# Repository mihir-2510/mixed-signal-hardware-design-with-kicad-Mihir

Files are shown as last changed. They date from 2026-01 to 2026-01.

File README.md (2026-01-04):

# USB-C Single-Channel Signal Analyzer & Generator

## Description
This repository contains the hardware design for a **USB-C powered, single-channel Signal Analyzer and Signal Generator** intended for low-frequency (audio-band) applications. The board integrates precision analog signal conditioning, data converters, and a microcontroller to enable waveform generation and signal acquisition through a PC interface.

The project was developed by Mihir Patil (Electrical Engineer) as a part of the deliverables for *Mixed-Signal Hardware Design with KiCad* course by Philip Salmony and focuses on applying **real-world mixed-signal PCB design practices** including power-domain separation, grounding strategies, filtering, biasing, and EMC-aware layout.

The module can function as a compact lab instrument for experimentation, education, and prototyping.

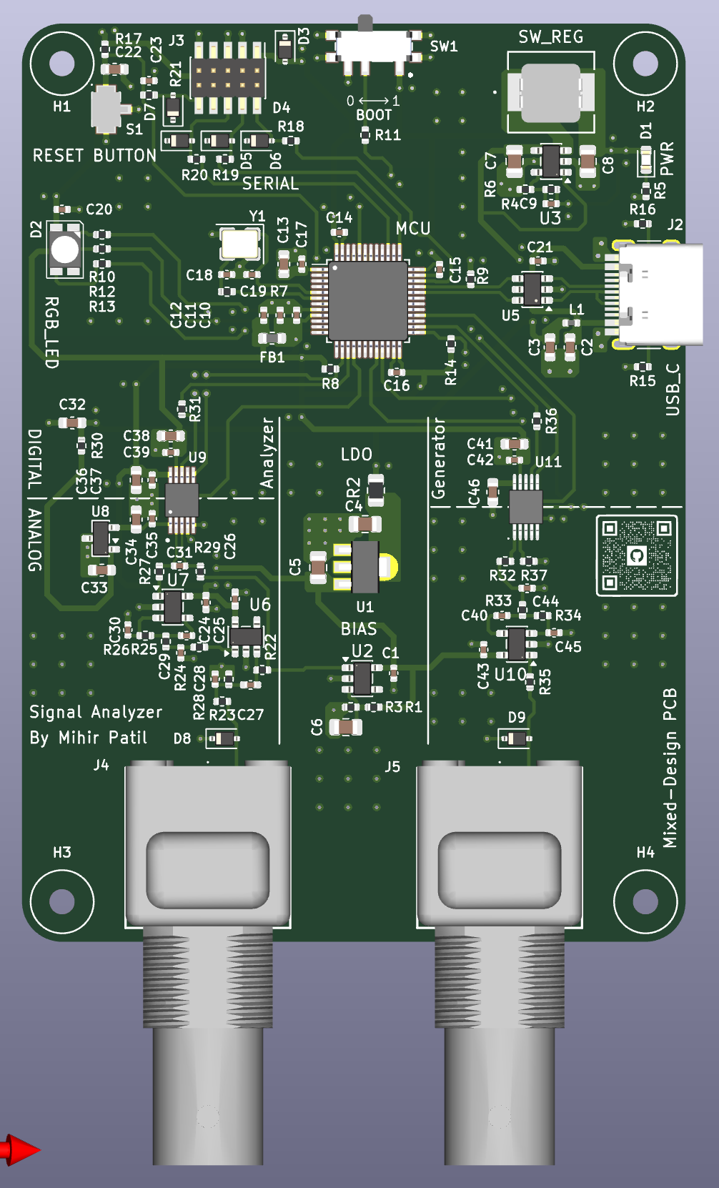
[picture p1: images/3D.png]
PCB 3D View


---

## Components

### Microcontroller
- STM32F103 (ARM Cortex-M series)
- USB 2.0 Full-Speed device
- SPI interfaces for ADC and DAC
- SWD interface for programming and debugging
- External crystal for accurate timing

### Analog-to-Digital Converter (ADC)
- 14-bit resolution
- Audio-band sampling rates
- High-impedance buffered input
- AC-coupled front end
- 3rd-order Sallen-Key Butterworth anti-aliasing filter
- Precision voltage reference for improved accuracy

### Digital-to-Analog Converter (DAC)
- 12-bit resolution
- SPI-controlled
- Reconstruction filter to suppress switching artifacts
- 50 Ω output impedance for signal integrity

### Power Architecture
- USB-C input power (5 V, < 500 mA)
- Switching buck regulator for digital 3.3 V rail
- Low-noise LDO regulator for analog 3.3 V rail
- Input LC filtering to suppress USB noise
- Dedicated mid-supply bias generator for single-supply analog stages

### Interfaces & Peripherals
- USB-C with CC resistors and ESD protection
- BNC connectors for signal input and output
- RGB status LED
- Reset and boot configuration buttons
- SWD debug header with protection components

---

## PCB Layout

The PCB was designed following mixed-signal layout best practices:
- Clear separation of analog and digital sections
- Dedicated analog and digital power domains
- Short return paths and solid ground referencing
- Careful placement of ADC/DAC front-end components
- EMI-aware routing for USB and high-speed digital lines

### Top-Level Board Layout
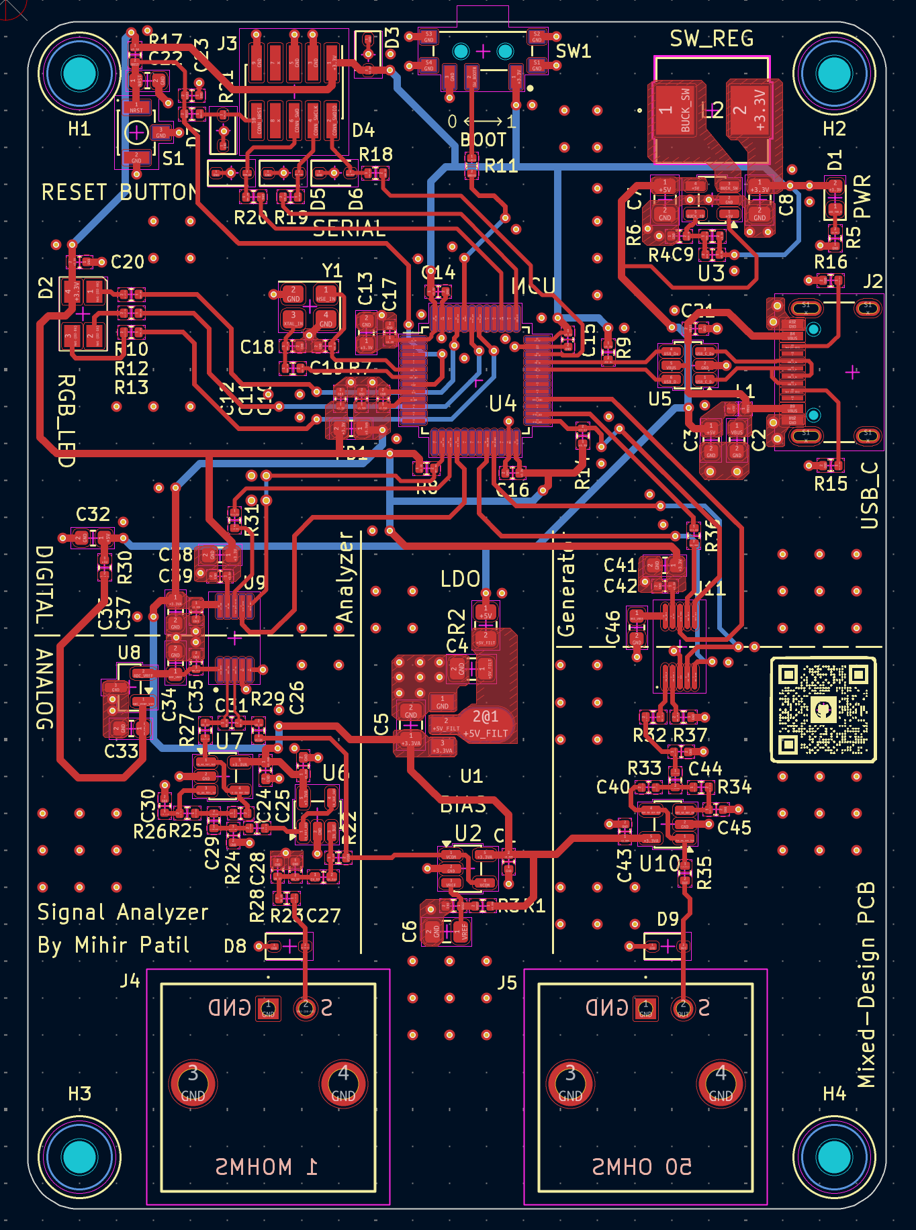
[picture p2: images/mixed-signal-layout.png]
PCB Layout


---

## Schematics

### Analog Front-End & ADC
High-impedance input buffer, RF filtering, AC coupling, and 3rd-order Butterworth anti-aliasing filter feeding the 14-bit ADC.

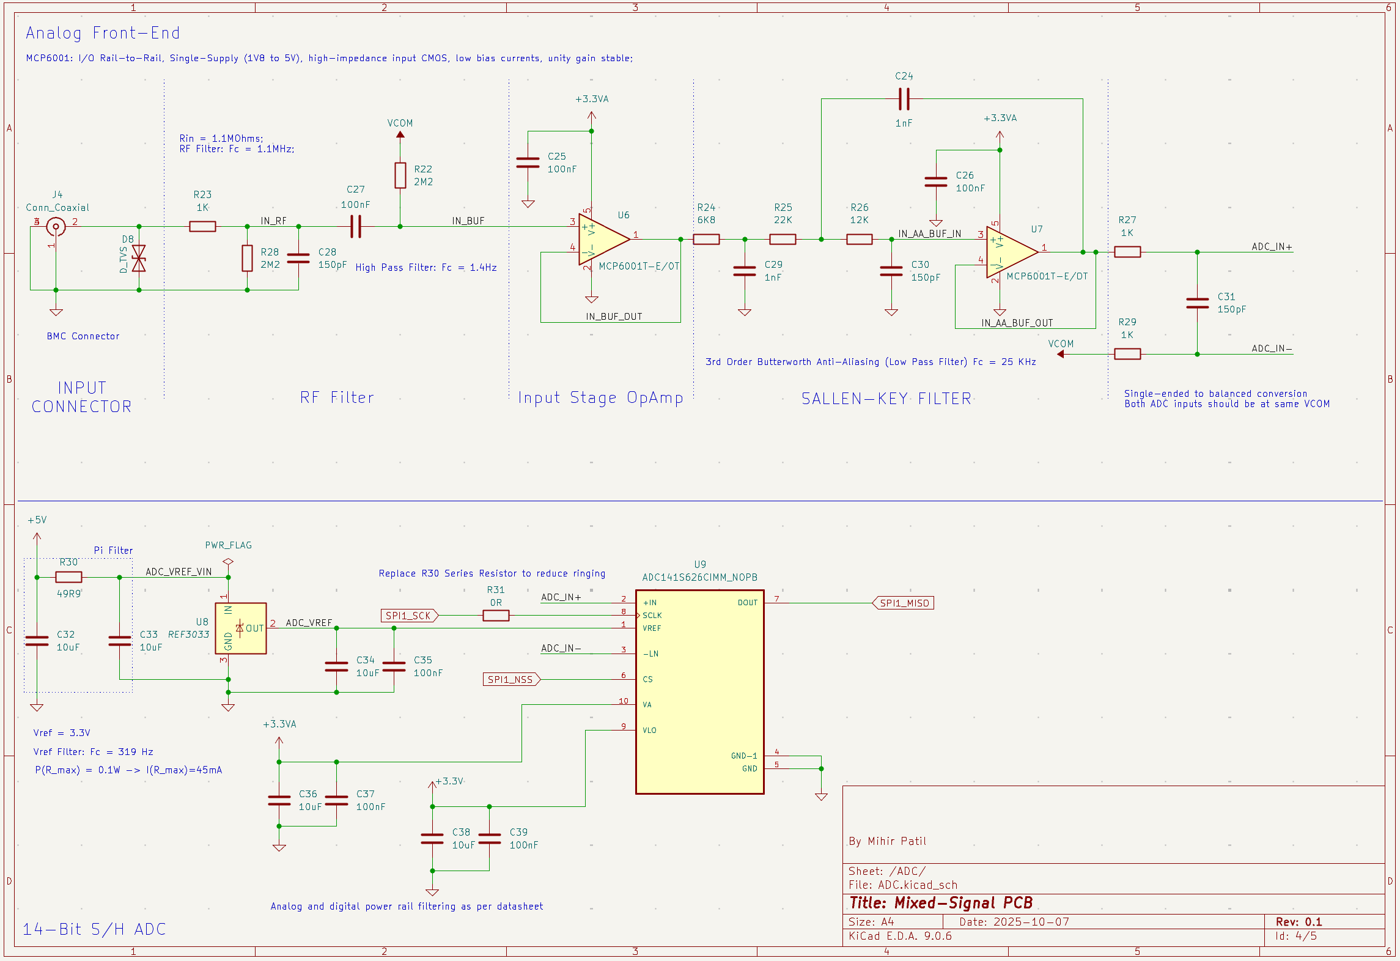
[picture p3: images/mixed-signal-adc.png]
Analog Front-End & ADC


---

### DAC & Analog Output Stage
DAC with reconstruction filter, output buffer, and 50 Ω output termination for clean waveform generation.

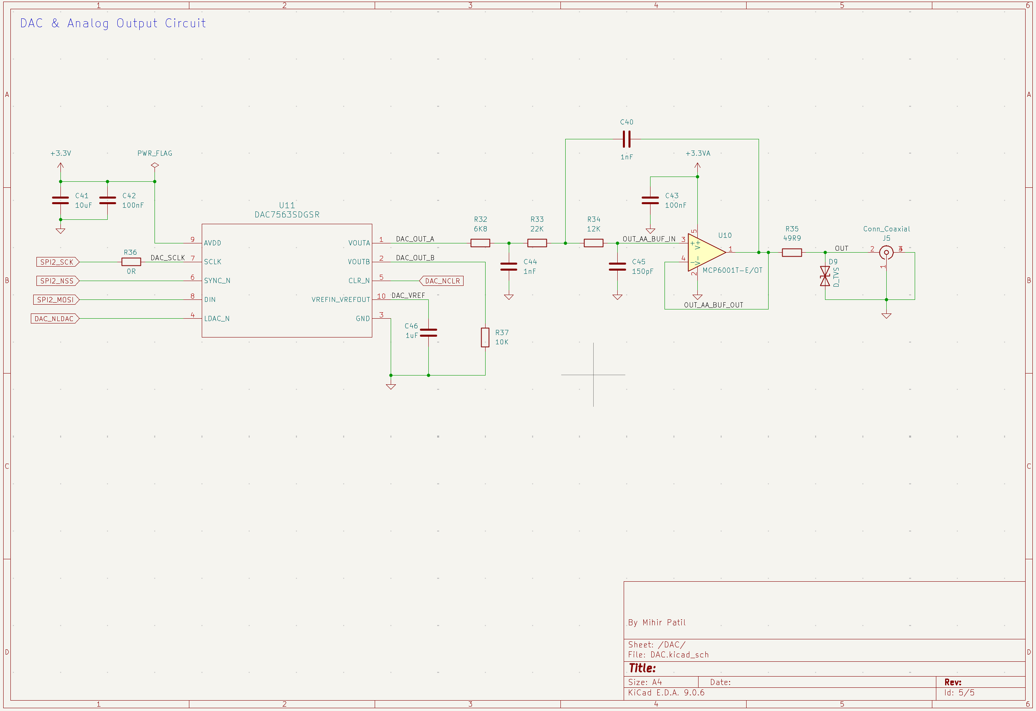
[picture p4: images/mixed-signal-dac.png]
DAC & Analog Output


---

### Microcontroller, USB-C & Debug
STM32 MCU core with USB-C interface, SWD debug circuitry, clocking, reset, and status LEDs.

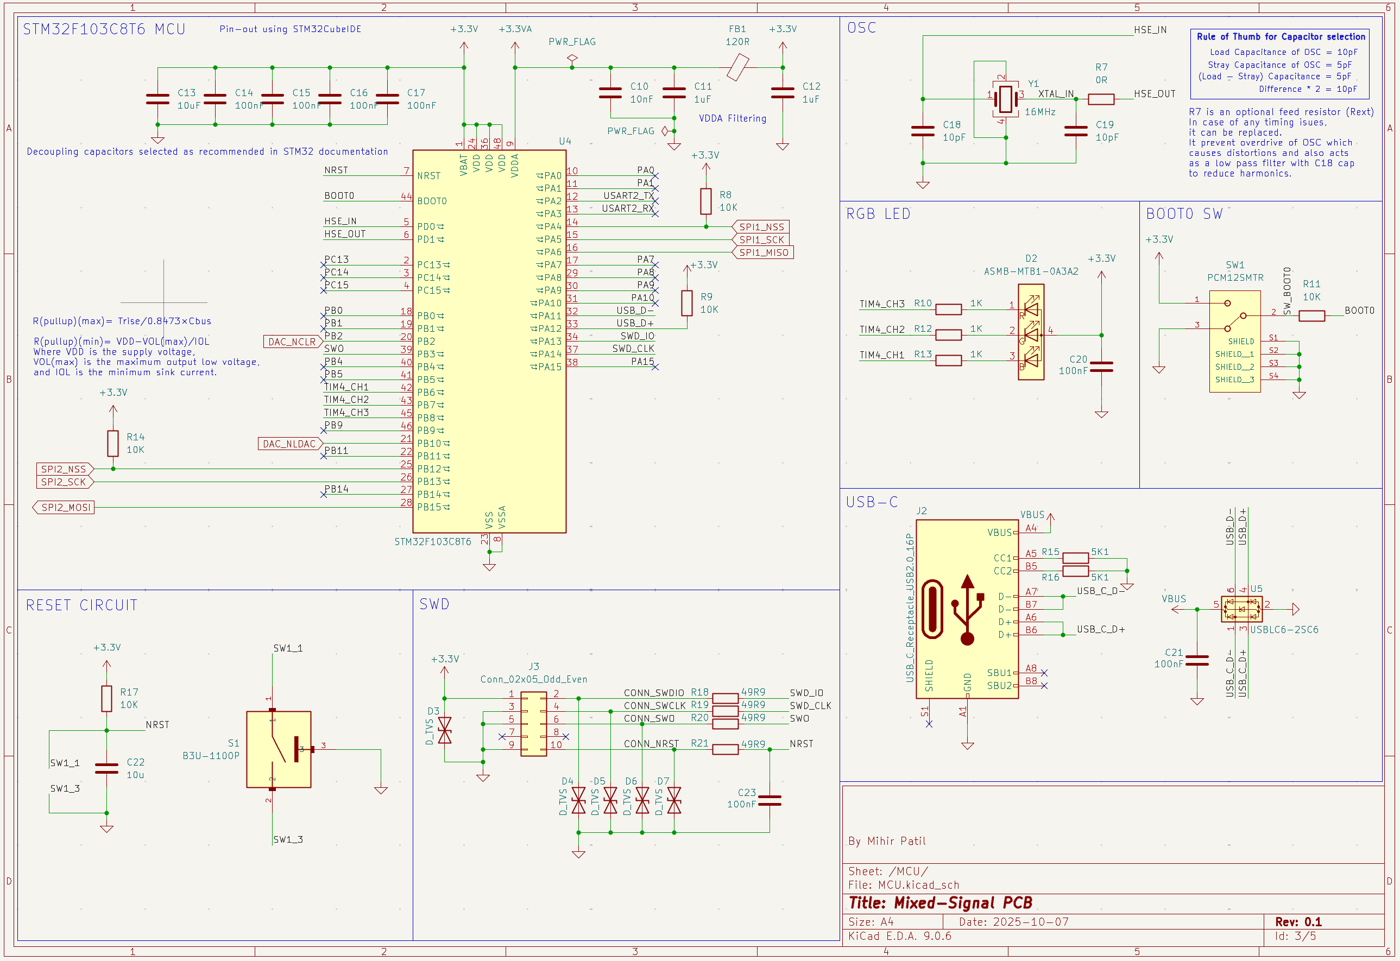
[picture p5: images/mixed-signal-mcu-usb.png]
MCU & USB


---

### Power Supply & Bias Generation
USB-C input filtering, buck regulator for digital rail, LDO for analog rail, and mid-supply bias generator.

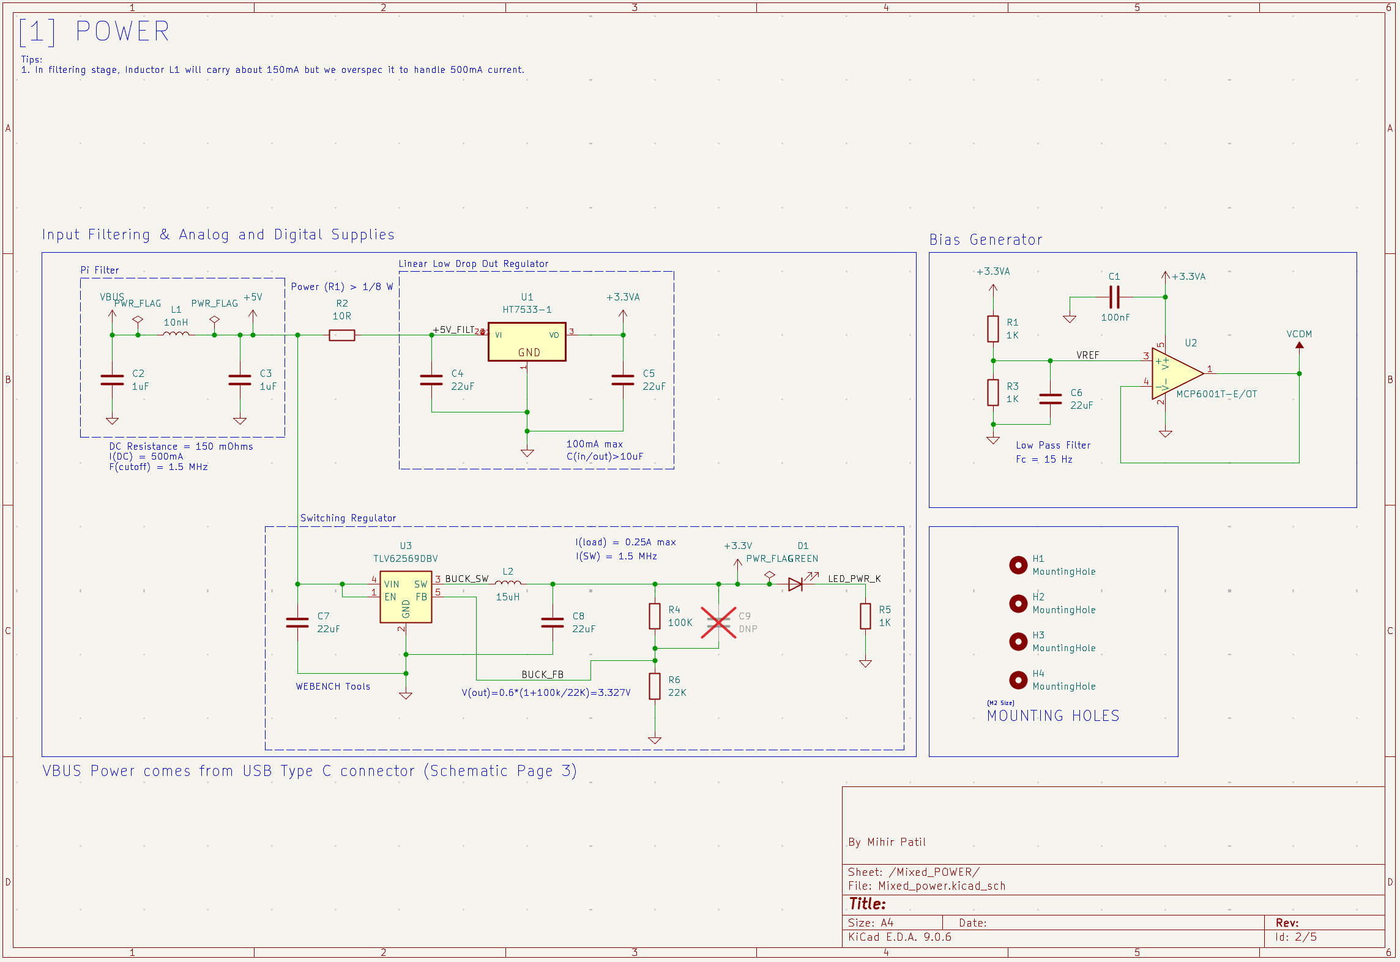
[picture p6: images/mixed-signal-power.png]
Power & Bias


---

## Use Cases

- **Low-Frequency Signal Analyzer**  
  Capture and inspect audio-band signals with proper buffering, filtering, and quantization.

- **Arbitrary Signal Generator**  
  Generate sine, square, and custom waveforms for testing analog circuits.

- **Educational Mixed-Signal Platform**  
  Demonstrates practical ADC/DAC interfacing, analog front-end design, and power integrity concepts.

- **PC-Based Measurement Tool**  
  Can be used as a simple oscilloscope or waveform generator when paired with host-side software.

---

## References

- Mixed-Signal Hardware Design with KiCad  
  Course by Philip Salmony  
  https://fedevel.com/courses/mixed-signal-hardware-design-with-kicad

- Phil’s Lab  
  https://www.phils-lab.net  
  https://www.youtube.com/@PhilsLab

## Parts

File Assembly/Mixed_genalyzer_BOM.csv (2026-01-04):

DESIGNATOR | QTY | Value | DNP | Exclude from BOM | Exclude from Board | Footprint | Datasheet | MANUFACTURER | Manufacturer_Part_Number | LCSC Part #
C1,C14,C15,C16,C17,C20,C21,C23,C35,C37,C39,C42,C43 | 13 | 100nF |  |  |  | Capacitor_SMD:C_0402_1005Metric | ~ | AIDE CAPACITOR | 0402X7R104K250NT | C48579248
C2,C3,C46 | 3 | 1uF |  |  |  | Capacitor_SMD:C_0603_1608Metric | ~ | AIDE CAPACITOR | 0603X5R105K160NT | C49326357
C4,C5,C6,C7,C8 | 5 | 22uF |  |  |  | Capacitor_SMD:C_0805_2012Metric | ~ | AIDE CAPACITOR | 0805X5R226M160NT | C49326686
C10 | 1 | 10nF |  |  |  | Capacitor_SMD:C_0402_1005Metric | ~ | AIDE CAPACITOR | 0402X7R103K500NT | C48579246
C11,C12 | 2 | 1uF |  |  |  | Capacitor_SMD:C_0402_1005Metric | ~ | Samsung Electro-Mechanics | CL05A105KP5NNNC | C14445
C13,C32,C33,C34,C36,C38,C41 | 7 | 10uF |  |  |  | Capacitor_SMD:C_0603_1608Metric | ~ | AIDE CAPACITOR | 0603X5R106M100NT | C48579264
C18,C19 | 2 | 10pF |  |  |  | Capacitor_SMD:C_0402_1005Metric | ~ | YAGEO | CC0402JRNPO9BN100 | C106199
C22 | 1 | 10u |  |  |  | Capacitor_SMD:C_0603_1608Metric | ~ | AIDE CAPACITOR | 0603X5R106M100NT | C48579264
C24,C29,C40,C44 | 4 | 1nF |  |  |  | Capacitor_SMD:C_0402_1005Metric | ~ | FOJAN | FCC0402B102K500AT | C5137470
C25,C26,C27 | 3 | 100nF |  |  |  | Capacitor_SMD:C_0402_1005Metric_Pad0.74x0.62mm_HandSolder | ~ | AIDE CAPACITOR | 0402X7R104K160NT | C48579247
C28,C30,C31,C45 | 4 | 150pF |  |  |  | Capacitor_SMD:C_0402_1005Metric | ~ | FH | 0402B151K500NT | C1527
D1 | 1 | GREEN |  |  |  | LED_SMD:LED_0603_1608Metric | ~ | BrtLed | BL-HGK36G-AV-TRB | C5123500
D2 | 1 | ASMB-MTB1-0A3A2 |  |  |  | LED_SMD:LED_Avago_PLCC4_3.2x2.8mm_CW | https://docs.broadcom.com/docs/AV02-4194EN | Broadcom | ASMB-MTB1-0A3A2 | C2927824
D3,D4,D5,D6,D7,D8,D9 | 7 | D_TVS |  |  |  | Diode_SMD:D_SOD-323 | ~ | GOODWORK | PESD3V3L1BA | C22466620
FB1 | 1 | 120R |  |  |  | Inductor_SMD:L_0603_1608Metric | ~ | UNI-ROYAL | 0603WAF1200T5E | C22787
H1,H2,H3,H4 | 4 | MountingHole |  | Excluded from BOM |  | MountingHole:MountingHole_2.2mm_M2 | ~
J2 | 1 | USB_C_Receptacle_USB2.0_16P |  |  |  | Connector_USB:USB_C_Receptacle_HRO_TYPE-C-31-M-12 | https://www.usb.org/sites/default/files/documents/usb_type-c.zip | Global Connector Technology | USB4105-GF-A-120 | C5184243
J3 | 1 | Conn_02x05_Odd_Even |  |  |  | Connector_PinHeader_1.27mm:PinHeader_2x05_P1.27mm_Vertical_SMD | ~ | hanxia | HX PZ1.27-2x5P TP | C41376037
J4,J5 | 2 | Conn_Coaxial |  |  |  | BMC:03156401010 | ~ | kinghelm | KH-BNC50-3511 | C2837587
L1 | 1 | 10nH |  |  |  | Inductor_SMD:L_0402_1005Metric | ~ | ABRACON | AISC-0402-10NG-T | C186805
L2 | 1 | 15uH |  |  |  | 15uH_Inductor:IND_MWSA0603S_SNL | ~ | Sunltech | SLO0630H150MTT | C182182
R1,R3,R5,R10,R12,R13,R23,R27,R29 | 9 | 1K |  |  |  | Resistor_SMD:R_0402_1005Metric | ~ | YAGEO | RC0402FR-071KL | C106235
R2 | 1 | 10R |  |  |  | Resistor_SMD:R_0805_2012Metric | ~ | UNI-ROYAL | 0805W8F100JT5E | C17415
R4 | 1 | 100K |  |  |  | Resistor_SMD:R_0402_1005Metric | ~ | YAGEO | RC0402FR-07100KL | C60491
R6,R25,R33 | 3 | 22K |  |  |  | Resistor_SMD:R_0402_1005Metric | ~ | FOJAN | FRC0402F2202TS | C2909337
R7,R31,R36 | 3 | 0R |  |  |  | Resistor_SMD:R_0402_1005Metric | ~ | PANASONIC | ERJ2GE0R00X | C242160
R8,R9,R11,R14,R17,R37 | 6 | 10K |  |  |  | Resistor_SMD:R_0402_1005Metric | ~ | UNI-ROYAL | 0402WGF1002TCE | C25744
R15,R16 | 2 | 5K1 |  |  |  | Resistor_SMD:R_0402_1005Metric | ~ | UNI-ROYAL | 0402WGF5101TCE | C25905
R18,R19,R20,R21,R30,R35 | 6 | 49R9 |  |  |  | Resistor_SMD:R_0402_1005Metric | ~ | TyoHM | RMC040249.91%N | C325388
R22,R28 | 2 | 2M2 |  |  |  | Resistor_SMD:R_0402_1005Metric | ~ | FOJAN | FRC0402F2204TS | C2998080
R24,R32 | 2 | 6K8 |  |  |  | Resistor_SMD:R_0402_1005Metric | ~ | UNI-ROYAL | 0402WGF6801TCE | C25917
R26,R34 | 2 | 12K |  |  |  | Resistor_SMD:R_0402_1005Metric | ~ | UNI-ROYAL | 0402WGF1202TCE | C25752
S1 | 1 | B3U-1100P |  |  |  | B3U_1100P:SW_B3U-1100P |  | Omron | B3U-1100PM | C6467298
SW1 | 1 | PCM12SMTR |  |  |  | PCM12_SPDT:SW_PCM12SMTR |  | C&K | PCM12SMTR | C221841
U1 | 1 | HT7533-1 |  |  |  | HT7533_1:HT7533-1 |  | HOLTEK | HT7533-1 | C14289
U2,U6,U7,U10 | 4 | MCP6001T-E/OT |  |  |  | Package_TO_SOT_SMD:SOT-23-5 | https://ww1.microchip.com/downloads/en/DeviceDoc/MCP6001-1R-1U-2-4-1-MHz-Low-Power-Op-Amp-DS20001733L.pdf | MICROCHIP | MCP6001T-E/OT | C29429
U3 | 1 | TLV62569DBV |  |  |  | Package_TO_SOT_SMD:SOT-23-5 | http://www.ti.com/lit/ds/symlink/tlv62569.pdf | TI | TLV62569DBVR | C141836
U4 | 1 | STM32F103C8T6 |  |  |  | STM32F103C8T6:QFP50P900X900X160-48N | https://www.st.com/resource/en/datasheet/stm32f103c8.pdf | ST | STM32F103C8T6 | C8734
U5 | 1 | USBLC6-2SC6 |  |  |  | Package_TO_SOT_SMD:SOT-23-6 |  | ST | USBLC6-2SC6 | C7519
U8 | 1 | REF3033 |  |  |  | Package_TO_SOT_SMD:SOT-23 | http://www.ti.com/lit/ds/symlink/ref3033.pdf | TI | REF3033AIDBZR | C36658
U9 | 1 | ADC141S626CIMM_NOPB |  |  |  | ADC141S626CIMM_NOPB:SOP50P490X110-10N |  | TI | ADC141S626CIMM/NOPB | C206494
U11 | 1 | DAC7563SDGSR |  |  |  | DAC7563SDGSR:DGS0010A_N | https://www.ti.com/lit/gpn/dac7563 | TI | DAC7563SDGSR | C601656
Y1 | 1 | 16MHz |  |  |  | Crystal:Crystal_SMD_3225-4Pin_3.2x2.5mm | ~ | Huiyuan crystal | HY16MSMD3225HB1R30 | C7275097

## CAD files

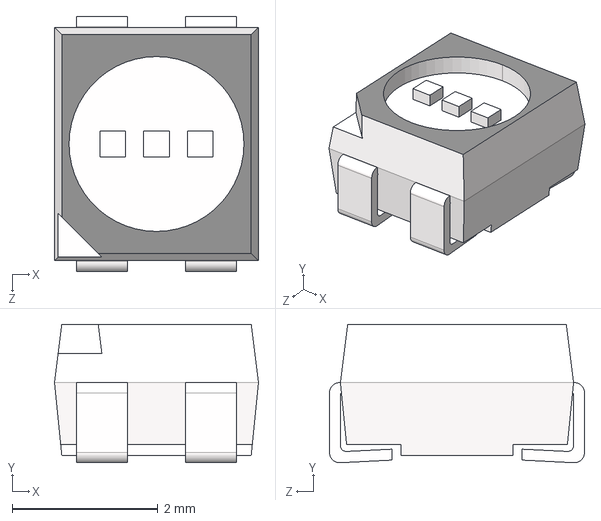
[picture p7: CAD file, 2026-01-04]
Components/ASMB-MTB1-0A3A2_RGB_LED/3D/ASMB-MTB1-0A3A2.stp
2.80 x 1.90 x 3.50 mm

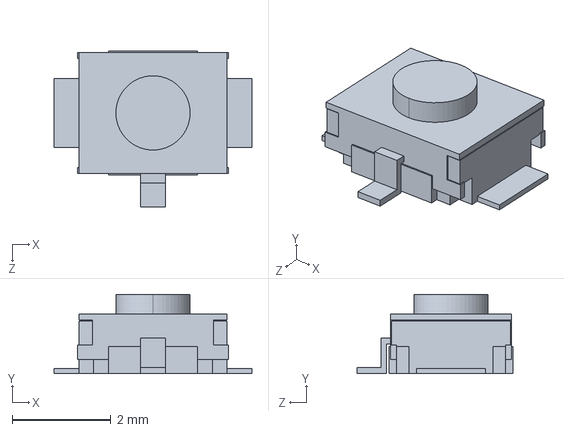
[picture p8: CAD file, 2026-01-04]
Components/B3U_1100P_button/B3U-1100P.STEP
4.00 x 1.60 x 3.15 mm

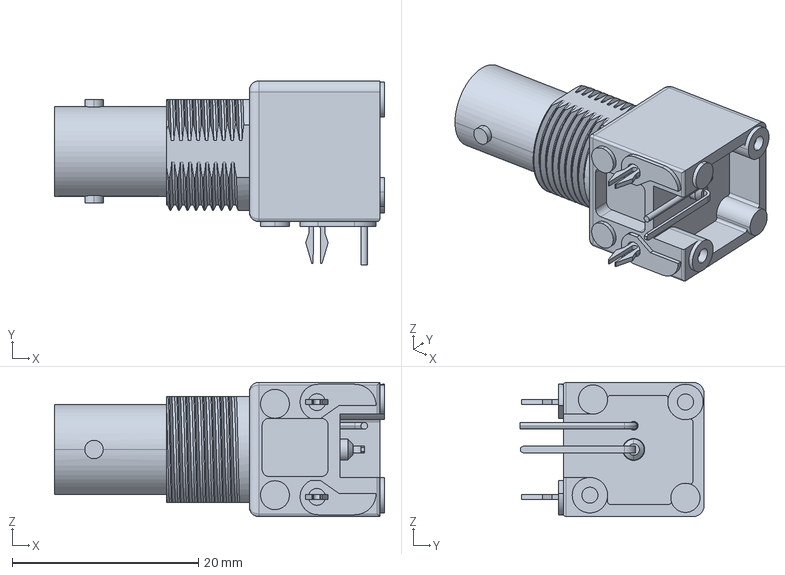
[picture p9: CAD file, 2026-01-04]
Components/BMC_CONN_031_5640_1010/031-5640-1010.stp
35.4 x 19.8 x 14.4 mm

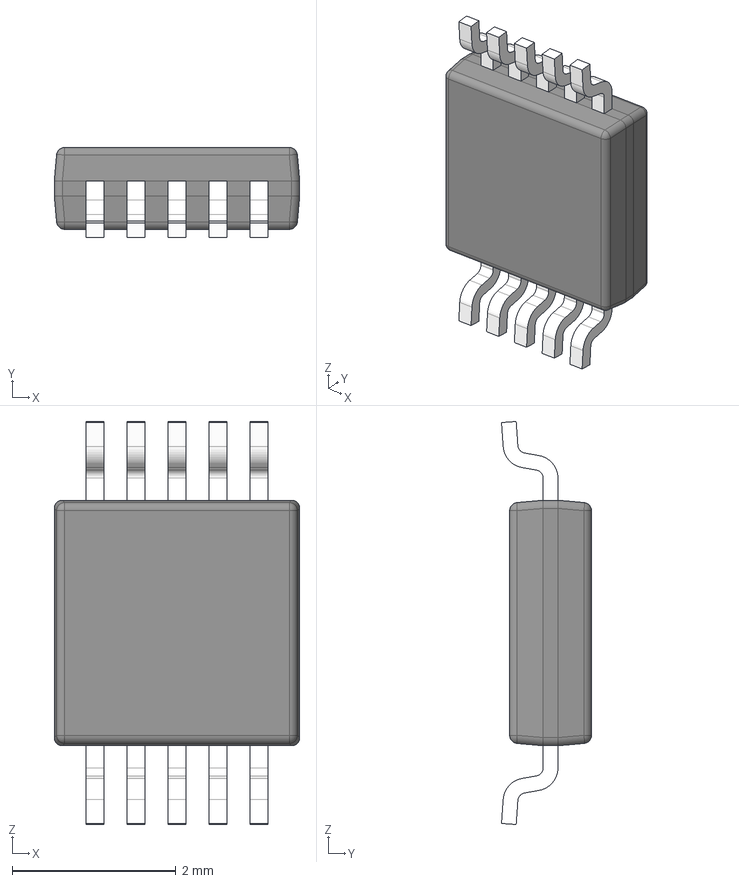
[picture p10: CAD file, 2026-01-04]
Components/DAC7563SDGSR/DGS0010A.stp
3.00 x 1.10 x 4.93 mm
BODY-SO
LEAD-SO x 10
PIN1-ID

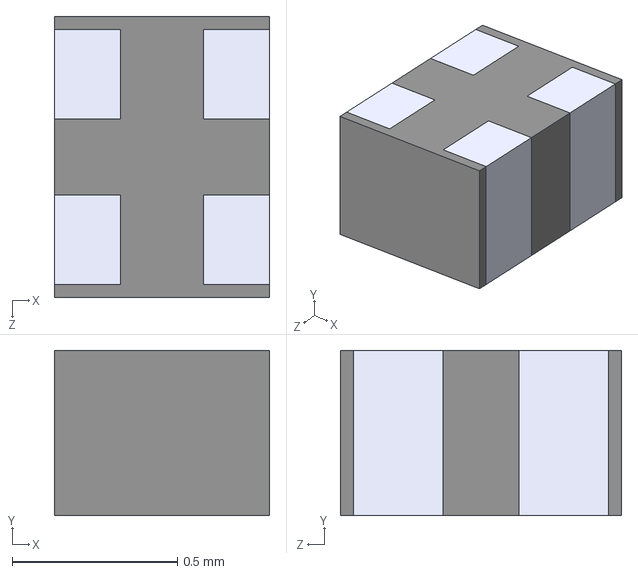
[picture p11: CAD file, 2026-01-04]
Components/DLM0NSN900HY2D_CMChoke/DLM0NSN900HY2D.step
0.65 x 0.5 x 0.85 mm

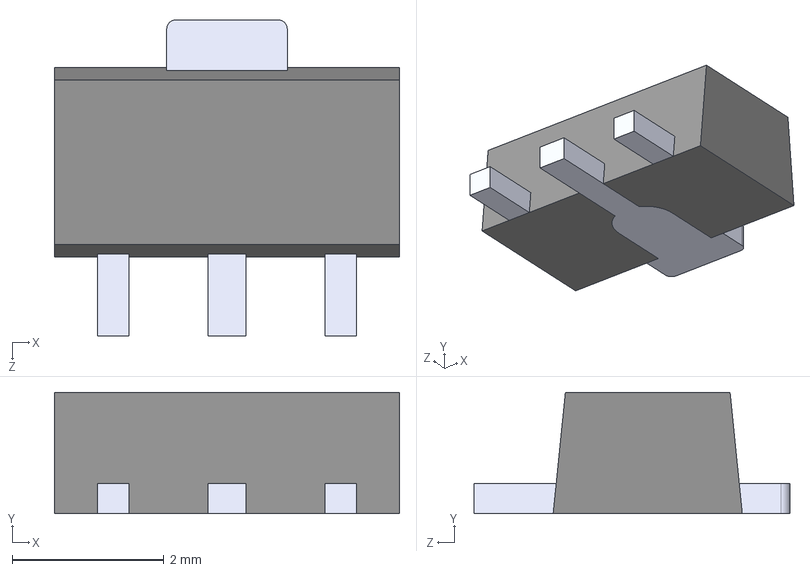
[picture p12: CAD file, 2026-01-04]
Components/HT7533-1/HT7533-1--3DModel-STEP-510211.STEP
4.55 x 1.60 x 4.17 mm

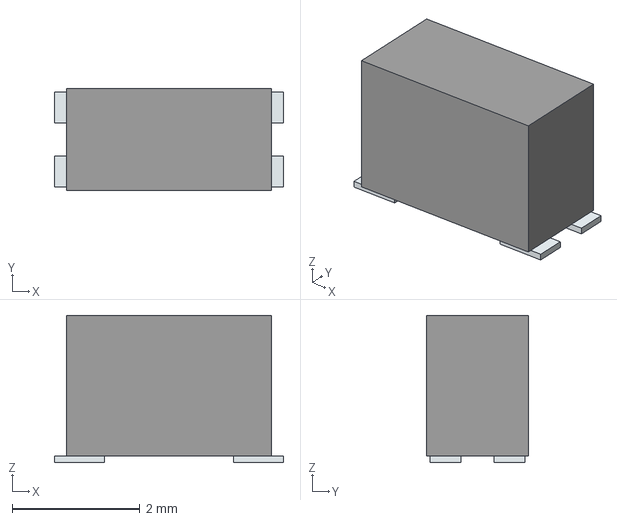
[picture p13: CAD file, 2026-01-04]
Components/LIB_SRF3216A-900Y/3D/SRF3216A-900Y.stp
3.58 x 1.60 x 2.30 mm
Pins

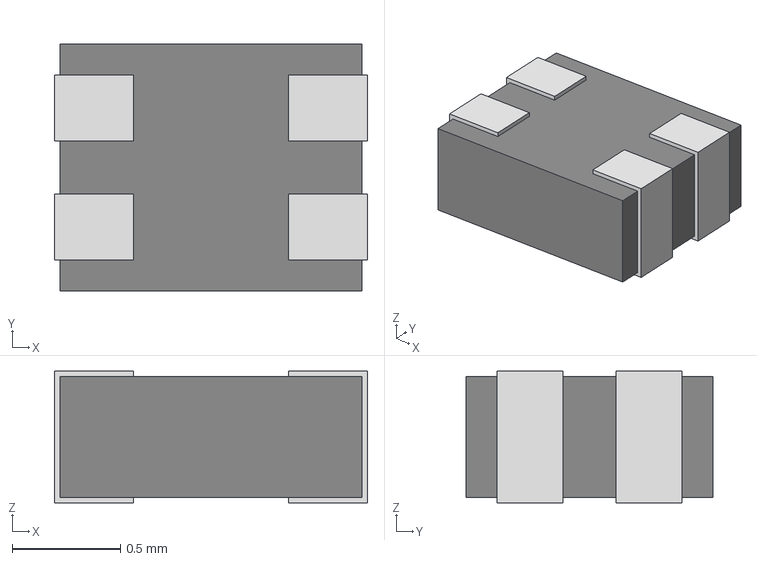
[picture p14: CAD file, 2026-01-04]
Components/MCZ1210AH900L2TA0G/MCZ1210AH_L2_TDK.step
1.45 x 1.14 x 0.61 mm

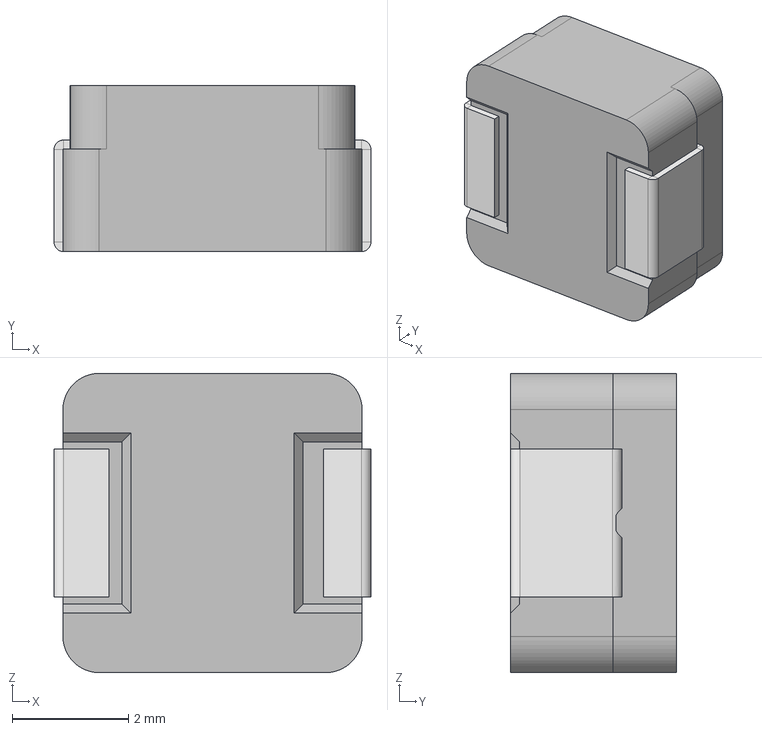
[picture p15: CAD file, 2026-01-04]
Components/MWSA0603S_15uH_Inductor/Inductor_15uH_Vishay_3D/ihlp2020czer4r7m01.stp
5.45 x 2.86 x 5.15 mm

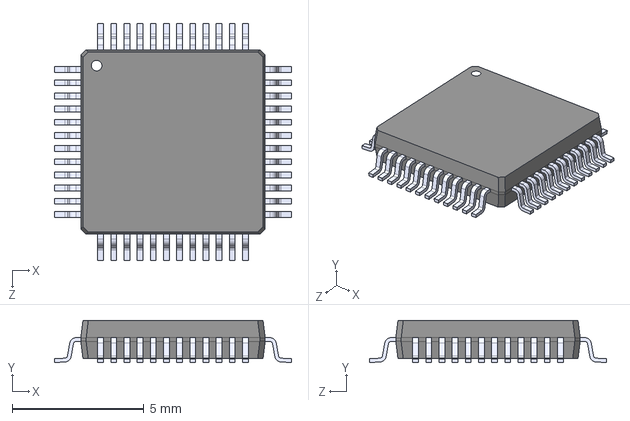
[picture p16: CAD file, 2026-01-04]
Components/STM32F103C8T6/STM32F103C8T6.step
9.00 x 1.60 x 9.00 mm

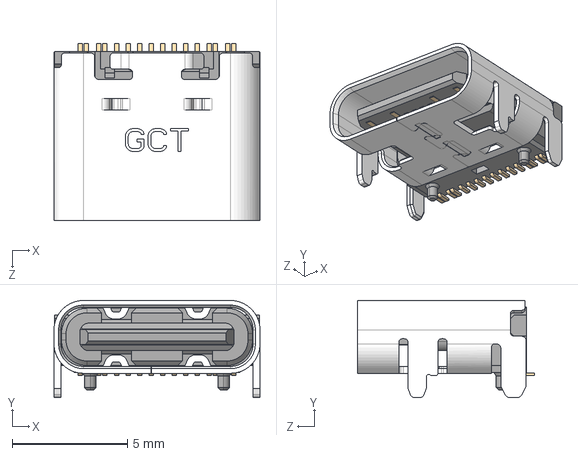
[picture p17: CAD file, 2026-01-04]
Components/USB4105-GF-A/3D/USB4105-GF-A.stp
8.94 x 4.21 x 7.70 mm
HSG_默认

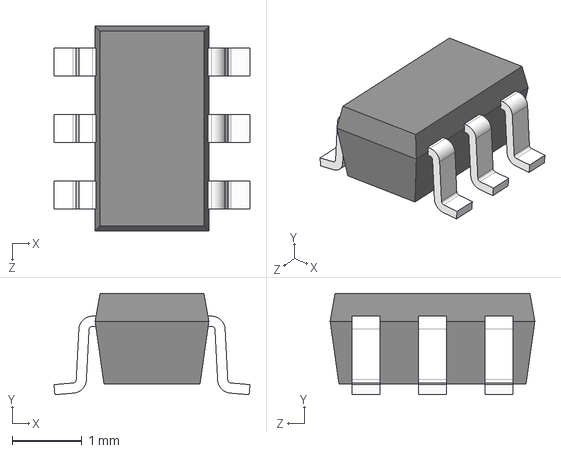
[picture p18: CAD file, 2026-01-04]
Components/USBLC6-2SC6/USBLC6-2SC6.step
2.80 x 1.45 x 2.92 mm

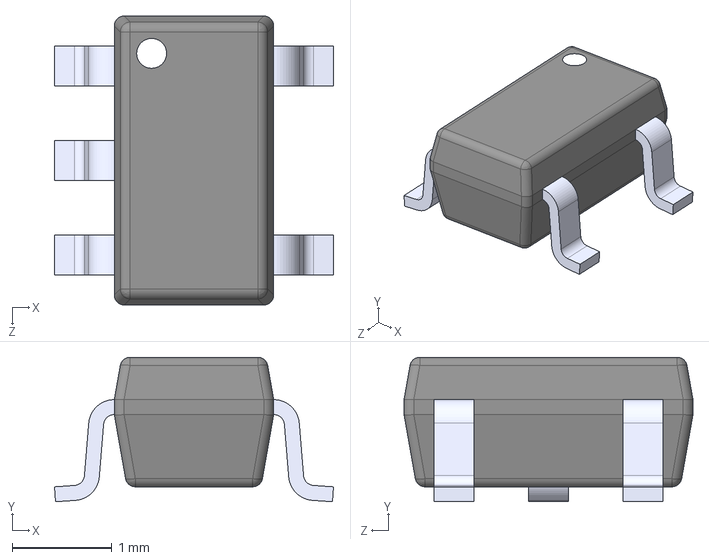
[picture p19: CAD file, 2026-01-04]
Components/TLV62569DBVR/TLV62569DBVR.step
2.80 x 1.45 x 2.90 mm

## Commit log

2026-01-04 Revise README for USB-C Signal Analyzer & Generator
    Updated the README to provide a detailed description of the USB-C Single-Channel Signal Analyzer and Generator, including components, PCB layout, schematics, use cases, and references.
2026-01-04 Added images folder containing schematic and layout images
2026-01-04 Added Component files, Assembly files and Gerber files for the Mixed-design board
    [031-5640-1010.stp, ADC141S626CIMM_NOPB.step, ASMB-MTB1-0A3A2.stp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]
